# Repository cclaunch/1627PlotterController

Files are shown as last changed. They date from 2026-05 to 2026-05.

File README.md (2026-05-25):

Attaching a 1627 Plotter to an IBM 1130 system required the installation of an IBM double width SLT card 5806223 into
gate A-C1 in slots M4/M5. The 1627 was an IBM badged version of the Calcomp 565 or 563 plotters.

This project provides a functional equivalent to that IBM SLT card that can be plugged into the IBM 1130 to add 
the controller logic so that software can command plotter movements and see its status in the same way as
the IBM card. PCBWay.com sponsored production of the main printed circuit board 
during development of this project. The results were excellent.

A connector is built to plug into the 1130 card compartment to wire the plotter into the system, 
in conjunction with an SMS power paddle card to plug into the SMS power connector block.

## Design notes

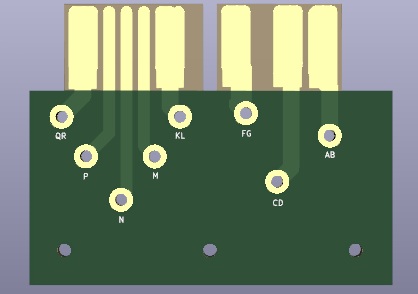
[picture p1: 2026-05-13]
sms power image.jpg

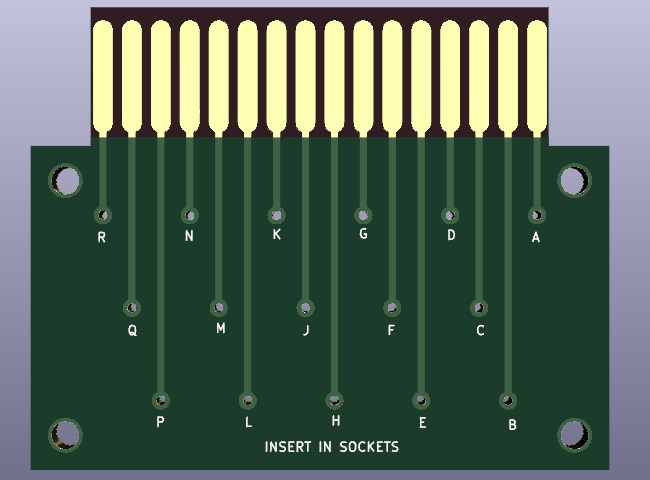
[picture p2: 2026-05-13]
sms signal paddle image.jpg

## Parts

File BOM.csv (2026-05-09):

Index | DigiKey Part # | Manufacturer Part Number | Manufacturer | Description | Quantity | Unit Price | Extended Price
1 | 1286-1205-ND | 410-376 | DIgilent | CMOD S7: BREADBOARDABLE SPARTAN7 | 1 | $99.00 | $99.00
2 | 497-6447-2-ND | LD1117S50TR | STM Microelectronics | IC REG LINEAR 5V 1.2A SOT-223 | 1 | $0.39 | $0.39
3 | 1276-1066-1-ND | CL21B105KAFNNNE | Samsung | CAP CER 1UF 25V X7R 0805 | 2 | $0.08 | $0.16
4 | RR12P1.0KDCT-ND | RR1220P-102-D | Susumu | RES SMD 1K OHM 0.5% 1/10W 0805 | 6 | $0.04 | $0.22
5 | 296-1630-1-ND | SN74LS05DR | Texas Instruments | IC INVERTER 6CH 1-INP 14SOIC | 1 | $0.83 | $0.83
6 | 296-14877-1-ND | SN74LS07DR | Texas Instruments | IC BUFF NON-INVERT 5.25V 14-SOIC | 1 | $0.59 | $0.59
7 | 20KDACT-ND | ERA-6AEB203V | Panasonic | RES SMD 20K OHM 0.1% 1/8W 0805 | 1 | $0.14 | $0.14
8 | A129757CT-ND | CRGCQ0805F4K7 | TE Connectivity | RES 4.7K OHM 1% 1/8W 0805 | 1 | $0.10 | $0.10
9 | RC0805FR-071K69L | RC0805FR-071K69L | Yageo | RES 1.69K OHM 1% 1/8W 0805 | 1 | $0.10 | $0.10
10 | RC0805FR-071K8L | RC0805FR-071K8L | Yageo | RES 1.8K OHM 1% 1/8W 0805 | 1 | $0.10 | $0.10
11 | ERA-6AEB332V | ERA-6AEB332V | Panasonic | RES SMD 3.3K OHM 0.1% 1/8W | 1 | $0.10 | $0.10
12 | KGM21NR71H104KT | KGM21NR71H104KT | Kyocera | CAP CER 0.1UF 50V X7R 0805 | 3 | $0.08 | $0.24
13 | A1921-ND | 640456-2 | TE Connectivity | CONN HEADER VERT 2POS 2.54MM | 1 | $0.13 | $0.13
14 | JLCPCB.com | W202411242236863 | Carl Claunch | SMS power card | 1 | $4.47 | $4.47
15 | ebay | SK19-23C | Cannon | Cannon 19 pin cable connector female | 1 | $23.49 | $23.49
16 | Mouser 571-1-102056-2 | 1-102056-2 | TE Connectivity | MODIV 24 pin connector | 1 | $6.39 | $6.39
17 | Mouser 571-1044808 | 104480-8 | TE Connectivity | socket pins 26-22 AWG | 24 | $0.33 | $7.94
 |  |  |  | Fedex Digikey and Mouser shipment charge | 2 | $6.99 | $13.98
 |  |  |  | tax @ 7% |  |  | $10.11
 |  |  |  | PCB + shipping charge | 0.2 | 74 | $14.80
 |  |  |  |  |  | subtotal | $183.28

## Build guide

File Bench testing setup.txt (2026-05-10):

Using Arduino Uno driver to bench test the plotter controller card

OVERVIEW
This code will drive signals that can put the plotter controller card
through its paces. The Uno produces 5V signals, so level shifting is
recommended via an open collector buffer chip and pullup resistor.

Six inputs on the analog pin side of the UNO are used with pushbuttons
to activate one of the actions. They have an internal pullup thus 
the pushbutton needs to have the input grounded except when pressed.

The reset button will put the card in a reset as occurs when the 1130
powers up or when the RESET button on the 1130 console is depressed.

The do drum up button will command the plotter to move the drum up one
position, followed by an XIO Sense Device so that you can verify
the busy bit (14) is set and operation complete (0) is not set
in the DSW. The interrupt request output pin of the controller
card will not go active low until 3.8 ms (5.8 ms when model 2
jumper is installed). Interrupt request stays low until the
state is reset by pushing the sense reset button. 

The do raise button will command the plotter to raise pen up off
the paper, followed by an XIO Sense Device while the plotter
is still considered busy. The interrupt request pin on the 
controller card will not go active (drop to low) until 100 
ms has elapsed. 

The sense button will issue an XIO Sense Device to the plotter
controller card, with the output pins on the card dropping
DSW bit 0, DSW bit 14 and DSW bit 15 when those bits of the 
DSW are a 1. 

The sense reset button will issue an XIO Sense Device to 
the plotter with the reset bit 15 set in the IOCC. This 
will reset the interrupt request for level 3 - an output
pin on the controller card - returning it to logic high. 
The DSW will not have bit 0 active since the completion 
was just reset. 

The do pen right and pen lower button will command both
movements simultaneously. The pen right output pin on the controller
card will drop low for 1.9 ms (2.9 ms if the model 2 jumper
is installed on the card) then go back to logic high, but
the lower pen output pin will stay low for 50 ms. The
interrupt request pin on the card will not go low (active)
until 100 ms has passed. 

REQUIREMENTS
Arduino Uno
12V power supply
3V power supply
-24V power supply
two open collector hex buffer chips
method to connect to SLT card pins
4 pullup resistors 10K 
Oscilloscope or logic analyzer to see outputs
the controller card to be tested

OUTPUT PINS ON THE ARDUINO
0    N/C
1    N/C
2    T6
3    XIO Sense Device
4    XIO Sense Devices w/Reset 15
5    DC Reset
6    B Bit 0
7    B Bit 1
8    B Bit 2
9    B Bit 3
10   B Bit 4
11   B Bit 5
12   XIO Write
13   Area 5

INPUT PINS ON THE ARDUINO
buttons on breadboard to Arduino
with internal pullup activated
14/A0   reset
15/A1   do drum up
16/A2   do raise pen
17/A3   Sense
18/A4   Sense reset 15
19/A5   do pen right and pen lower

OUTPUT PINS ON THE CONTROLLER CARD
these are of different logic voltage levels. 
Some require an external pullup resistor.

Interrupt request B09 needs a pullup to 3V
DSW Bit 0 B10 needs a pullup to 3V
DSW Bit 14 B04 needs a pullup to 3V
DSW Bit 15 B05 needs a pullup to 3V

Pen Left J04 is inverted logic, at 12V except 0 when active
Pen Right G05 is inverted logic, at 12V except 0 when active
Drum Up J02 is inverted logic, at 12V except 0 when active
Drum Down J05 is inverted logic, at 12V except 0 when active
Pen Up D05 is inverted logic, at 12V except 0 when active
Pen Down D04 is inverted logic, at 12V except 0 when active

The controller card needs 12V supplied to pin G02 and ground
attached to pins D08 and J08. It will consider the plotter
to be offline and not ready unless -24V is fed through a 3.9K
resistor to pin B08. When that voltage through the resistor
is present, the controller will issue outputs to move
the plotter pen and drum. DSW bit 15 is logically 1 (0V)
if no voltage present on B08, logic 0 (3V) if -24 there.

INPUT PINS ON THE CARD
The attachments from the Arduino are level shifted to 
3V through the buffer chips in your bench test setup

XIO Write          J12
Area 5             J10
T6                 J13
DC Reset           D12
Sense Device       D07 and D11
Sense Reset bit 15 D09
B bit 0            B03
B bit 1            D10
B bit 2            D02
B bit 3            D13
B bit 4            D06
B bit 5            B02

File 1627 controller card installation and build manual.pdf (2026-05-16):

## Build and Installation Instructions

1627 Plotter attachment to IBM 1130

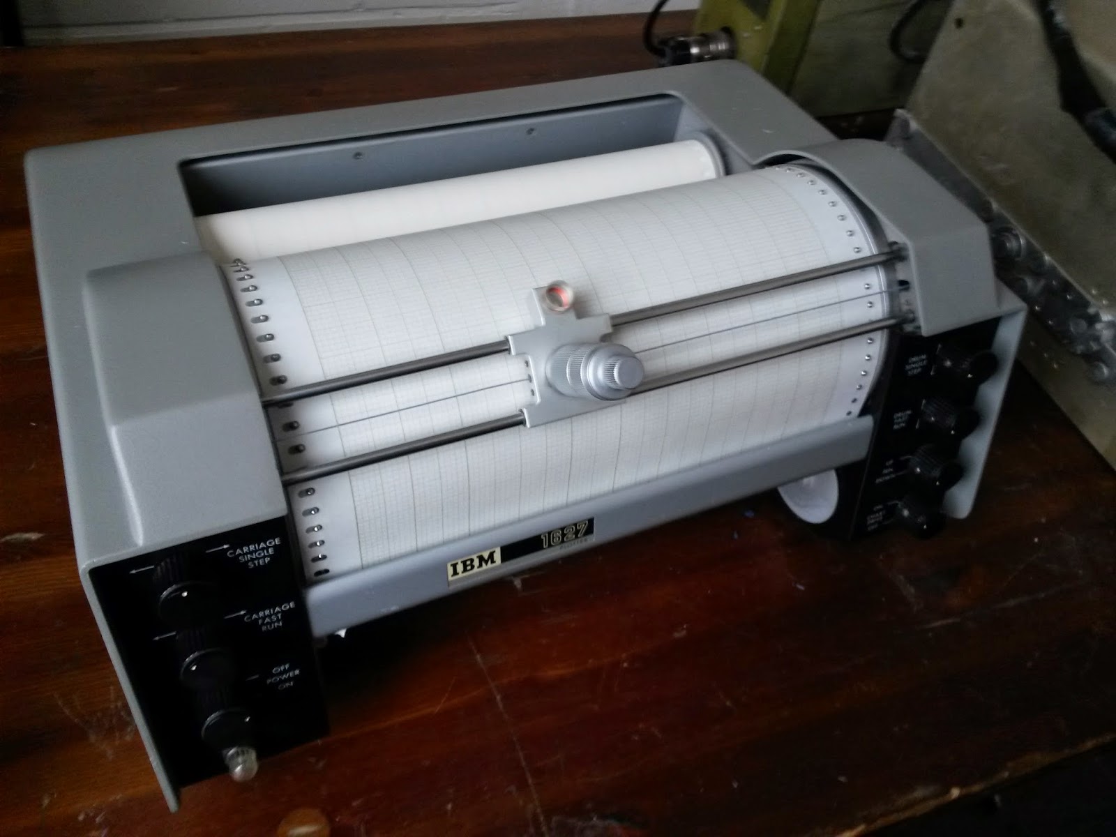
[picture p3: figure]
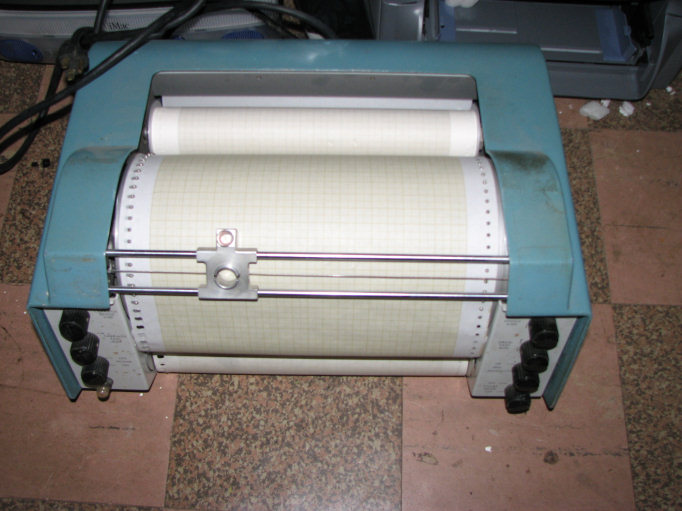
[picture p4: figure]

Carl V Claunch | 1 | Version 1

Plotter models this board can be used with

This board is designed to be used with the IBM 1627 model 1 or IBM 1627 model 2 plotters. These are private labeled versions of the Calcomp 565 and Calcomp 563 respectively.

Selecting the plotter model

To support the larger plotters - 1627 model 2 or Calcomp 563 - install a jumper across the two pins marked ‘model 2’ on the PCB. The jumper slows down the response to pen movements from 3.8 milliseconds to 5.8 milliseconds due to the larger drum size of those models. If the plotter is an IBM 1627 model 1 or a Calcomp 565, no jumper is installed on the pins.

1627 Plotter attachment to IBM 1130

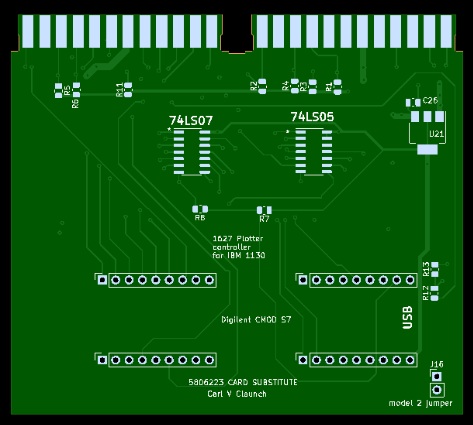
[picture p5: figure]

Carl V Claunch | 2 | Version 1

Building the card

It is recommended that the contacts be installed onto the printed circuit board before adding the other components. See the following section for how to source the contacts and how to solder them onto the board.

Next solder the resistors, capacitors and three integrated circuits on the PCB. The last step will be to install the daughterboard onto the PCB. Push the Digilent CMOD S7 FPGA board through the holes, ensuring that you have the USB connector end oriented properly. This board must lay low on the PCB to avoid mechanical interference with other SLT cards when it is in the compartment. Solder the FPGA board in place and trim the leads close to the back of the main PCB.

If not done already, the plastic covers are inserted over the two sockets and snapped into place. The card would then be ready for bench testing, installation in the IBM 1130 and testing on the system.

1627 Plotter attachment to IBM 1130

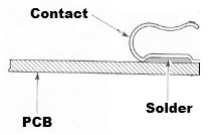
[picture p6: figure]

Carl V Claunch | 3 | Version 1

Installing contacts and cover on the substitute card

The card has space for 48 contacts to form the two 2x12 slot plugs. Generally the best way to get the contacts is to disassemble a donor Solid Logic Technology (SLT) card.

Remove the plastic cover over the 2x12 pin socket from which you can extract 24 contacts. The edges of the card slope outward toward the end which tends to hold the plastic cover in place. A small screwdriver can be used to bend the sides of the covers to allow them to be pulled off the card. Also save the plastic cover for re-use on the new card.

Unsolder contacts from the donor card(s) until you have the 48 needed for the plotter substitute controller card. A hot air rework tool on a heated rework table works best for this, but use any method you have that works.

The contact has a flat plate that solders onto the PCB pad and continues bending around and upward to provide a springy bit of metal that the SLT backplane pin can push against. Do not install the contact with the bend at the edge of the card, the open U shape should be at the edge.

1627 Plotter attachment to IBM 1130

Carl V Claunch | 4 | Version 1

First, using a solder paste with a higher melting point (e.g. 183 C), solder down the contacts on one side. Set the rework table to about 150 C and a hot air rework gun to over 183 C.

Lay solder paste on the pads on the side of the card you are working with first, then place all the contacts on that side sitting in roughly the correct position atop the paste.

Using the hot air rework gun, melt the pads while verifying that the contact slides into proper alignment once the solder has fully flowed. Work from one side to the other, until you have all the contacts lined up correctly and soldered to the board. A clamp or clip might be placed on the contact portion directly on the PCB pad, with the other side of the clamp/clip on the underneath portion of the PCB. That would assure better alignment but the key will be to heat long enough to be certain the solder paste is fully melted underneath the contact.

Using a second lower heat solder paste (e.g. 138 C), turn the rework table down to about 115C and the hot air rework gun to just a bit over 138
C. Once the table is at the proper temperature, lay the card with the other side’s pads facing you. Lay solder paste on the pads and place the remaining contacts in approximately the proper spot. If using a clamp or clips, add them now.

Using the hot air rework gun, melt the pads while verifying that the contact sits in proper alignment once the solder has fully flowed. Work from one side to the other, until you have all the contacts lined up correctly and soldered to the board.

1627 Plotter attachment to IBM 1130

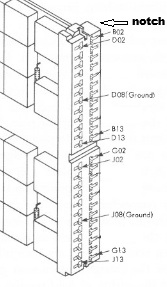
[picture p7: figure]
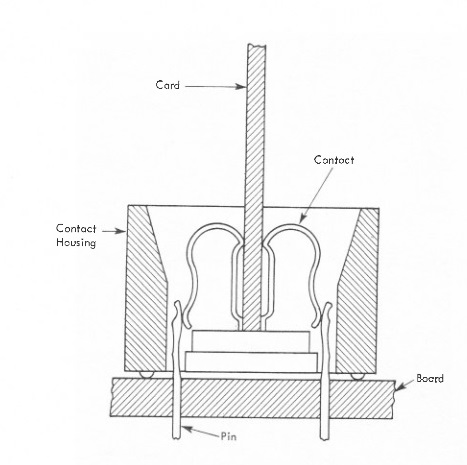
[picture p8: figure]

Carl V Claunch | 5 | Version 1

Slide the plastic covers over the contacts to finish the SLT slot plugs. The notch on the cover is on the side of the PCB away from the chips.

Do a test insertion into a vertical pair of open SLT slots in the 1130 to confirm that the card does snap down into place.

1627 Plotter attachment to IBM 1130

Carl V Claunch | 6 | Version 1

Load the logic into the FPGA

Load the CMOS S7 FPGA board with the memory configuration file to activate the logic for the plotter controller functionality. I use Xilinx Vivado, doing an autoconnect to the board through a USB cable, selecting the flash RAM that is listed as part of the discovered board, then programming the FPGA with the memory configuration file.

If the flash RAM chip on the CMOD S7 board is a MX25L3233F, then the FPGAload.mcs file included in the github project can be downloaded, otherwise a project must be built in Vivado to synthesize and generate the bitstream from the source files, then creating a memory configuration file to download to the RAM chip type that is built into your CMOD S7 board. A file on github explains how to generate IP and add additional source files to build the memory configuration file.

If you might ever use the USB serial link to capture movement commands from the card, there is a hardware modification needed to the CMOD S7 board (see later in this document) to safely connect when the card is in the IBM 1130.

Installing the substitute 5806223 controller card in the 1130

Once you are done with any visual inspection, continuity testing and possible bench testing, slide the double width card into slots M4 and M5 of Gate A, Compartment C1. Push down until it is securely in place.

1627 Plotter attachment to IBM 1130

Carl V Claunch | 7 | Version 1

Three alternative approaches to connecting the 1627 cable

A - The IBM 1130 system already has cabling installed between Gate A, Compartment C1, Slot N5 and slot PF6 of the SMS sockets for peripherals inside the 1130 system

B - you will wire up a cable between SMS socket slot PF6 and Gate A, Compartment C1 Slot N5

C - you will wire up a modern connector near Gate A, Compartment C1 into which the plotter signal cable will plug

1627 Plotter attachment to IBM 1130


Carl V Claunch | 8 | Version 1

Alternative A - using existing wiring in an 1130 system

Since the 1130 already has wiring from a socket in slot PF6 of the SMS peripheral connection block over to Slot N5 of Gate A, Compartment C1, you only need to connect the wiring from the plotter connector to an SMS paddle card that will be plugged into slot PF6.

A female 19 pin connector, Cannon SK19-23C, plugs into the rear of the plotter. It carries all the power and signal lines between the plotter and the 1130 system.

Create an SMS power paddle card and run 18 gauge stranded wire to it from the 19 pin connector:

Cannon pin 15 is connected to pad P of the power paddle card Cannon pin 17 is wired to pads F and G of the power paddle card Cannon pin 18 is wired to pads C and D of the power paddle card Cannon pin 14 is wired to pads K and L of the power paddle card

A SMS power paddle card has a notch cut in the card approximately where pads H and J would be on a normal SMS signal paddle card. This ensures that signal cards CANNOT fit into the power SMS sockets on the 1130 system. Gerber/drill files are provided to make this card as well as files to make an SMS signal paddle card used below.

1627 Plotter attachment to IBM 1130

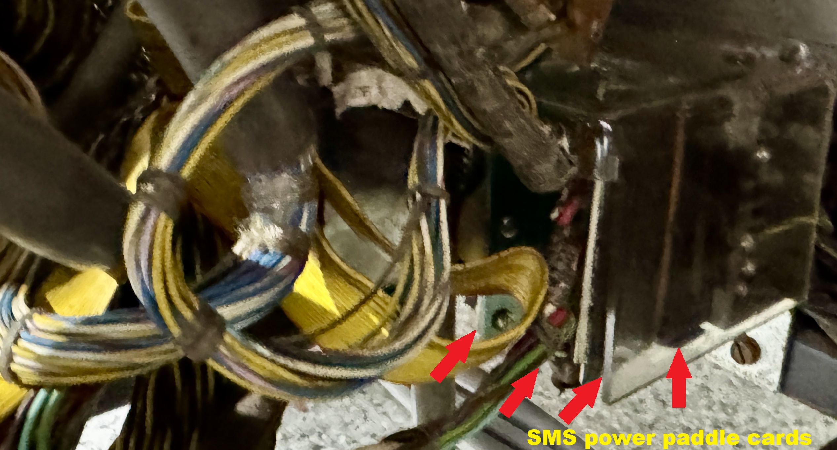
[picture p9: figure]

Carl V Claunch | 9 | Version 1

A regular SMS paddle card, used for the signal connections, is connected as follows using smaller gauge stranded wire:

Cannon pin 5 is wired to the signal paddle card PF6 pad R Cannon pin 6 is wired to the signal paddle card PF6 pad Q Cannon pin 7 is wired to the signal paddle card PF6 pad N Cannon pin 8 is wired to the signal paddle card PF6 pad P Cannon pin 11 is wired to signal paddle card PF6 pad M
Cannon pin 12 is wired to signal paddle card PF6 pad L
Cannon pin 16 is wired to signal paddle card PF6 pad G

Install a 3.9K resistor connected between PF6 pad G and PF6 pad C

Open the lower SMS socket block inside the IBM 1130, where peripheral power connections are made. Insert the power paddle card you manufactured into slot PP6. The correct slot is important as the power connections in the block can vary by location. . Close up the power socket block.

1627 Plotter attachment to IBM 1130

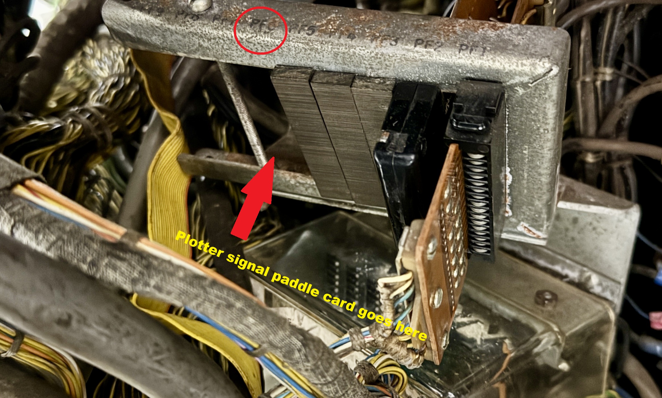
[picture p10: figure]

Carl V Claunch | 10 | Version 1

Open the upper SMS socket block that connects signal lines to peripherals. Insert the signal paddle card into slot PF6 of this block. Close up the socket block.

1627 Plotter attachment to IBM 1130

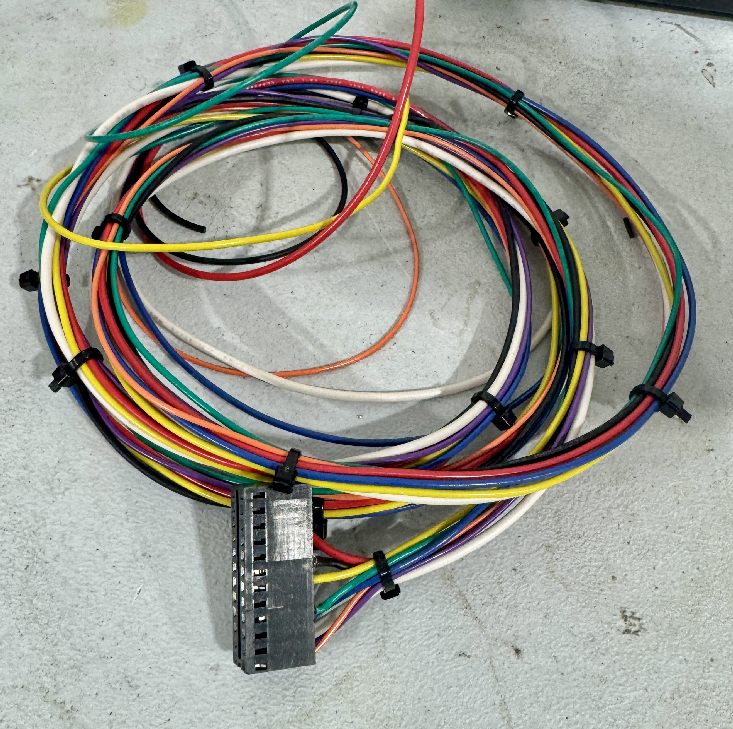
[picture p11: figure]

Carl V Claunch | 11 | Version 1

Alternative B - Adding wiring that matches the IBM approach

Construct the two paddle cards and the cable to the Cannon 19 pin connector using the instructions from Alternative A above. The additional work that must be done is to add a wire bundle between the SMS signal socket block slot PF6 and Gate A, Compartment C1, Slot N5 where the signals are connected to the Solid Logic Technology (SLT) backplane for that compartment.

Build an SLT connector that will plug into slot N5 - a source is provided in the bill of materials.

Using appropriate twisted pairs, routing one wire of each pair to the 1130 signal ground, connect:

Paddle socket position R is wired to N5 connector position B02 Paddle socket position Q is wired to N5 connector position D02 Paddle socket position N is wired to N5 connector position D04 Paddle socket position P is wired to N5 connector position B03 Paddle socket position M is wired to N5 connector position B04 Paddle socket position L is wired to N5 connector position D05 Paddle socket position C is wired to N5 connector position B10

1627 Plotter attachment to IBM 1130

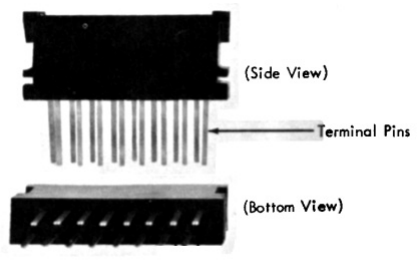
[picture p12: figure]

Carl V Claunch | 12 | Version 1

Install the female SMS socket in space PF6 of the upper SMS socket block. Plug the SMS signal paddle card you wired from the plotter (as covered in alternative A) into this socket. Close up the SMS signal socket block.

Plug the SLT connector end you just wired to the SMS female socket into Gate A, Compartment C1, Slot N5. See the instructions further down for how to do this.

1627 Plotter attachment to IBM 1130

Carl V Claunch | 13 | Version 1

Alternative C - modern connector for the signal connections

Use the instructions from alternative A to build an SMS power paddle card and wire it to the Cannon 19 pin connector. Install the SMS power paddle card in the lower SMS socket block as described in alternative A.

Buy any 8 pin male and female socket pair. Install the female socket on the 1130 gate A near Compartment C1. Build the SLT socket as described in alternative B.

Wire the 19 pin connector to the male socket:
Cannon pin 5 is wired to the socket pin 1
Cannon pin 6 is wired to the socket pin 2 Cannon pin 7 is wired to the socket pin 3 Cannon pin 8 is wired to the socket pin 4
Cannon pin 11 is wired to the socket pin 5
Cannon pin 12 is wired to the socket pin 6
Cannon pin 16 is wired to a 3.9K resistor whose other end is wired to the socket pin 7
Cannon pin 15 is wired to the socket pin 8 (also wired to the power SMS paddle card)

Connect the female socket:
socket pin 1 to N5 connector position B02
socket pin 2 to N5 connector position D02 socket pin 3 to N5 connector position D04 socket pin 4 to N5 connector position B03 socket pin 5 to N5 connector position B04
socket pin 6 to N5 connector position D05
socket pin 7 to N5 connector position B10
socket pin 8 to signal ground below the card compartment

1627 Plotter attachment to IBM 1130

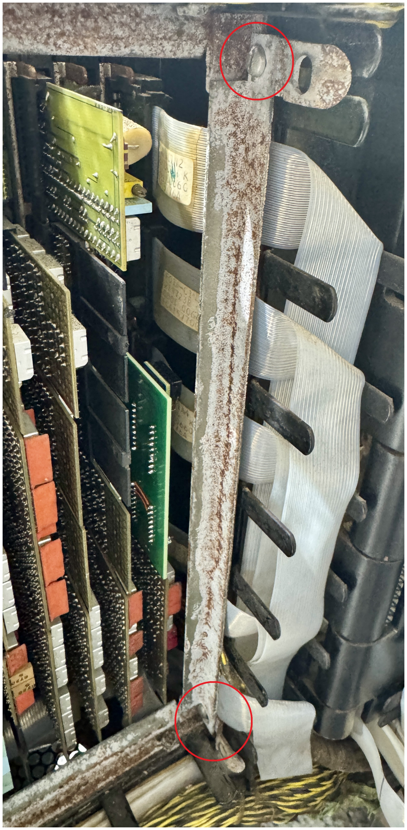
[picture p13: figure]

Carl V Claunch | 14 | Version 1

Installing the SLT connector in slot N5

Remove the card cover from compartment C1 of gate A. Loosen the two screws circled in red below that hold the right side support for the cover.

Plug the SLT connector into slot N5 and pass the wires to the right so that they will be held under the right side support when you re-install that part.

Secure the cable from the male connector where it exits the 1130 system to protect from someone accidentally pulling the connectors. I used twist ties to anchor the cable inside compartment C1 after the connector was plugged in, as well as anchoring the cable as it runs through the 1130 and at the exit point where the cable comes out of the machine.

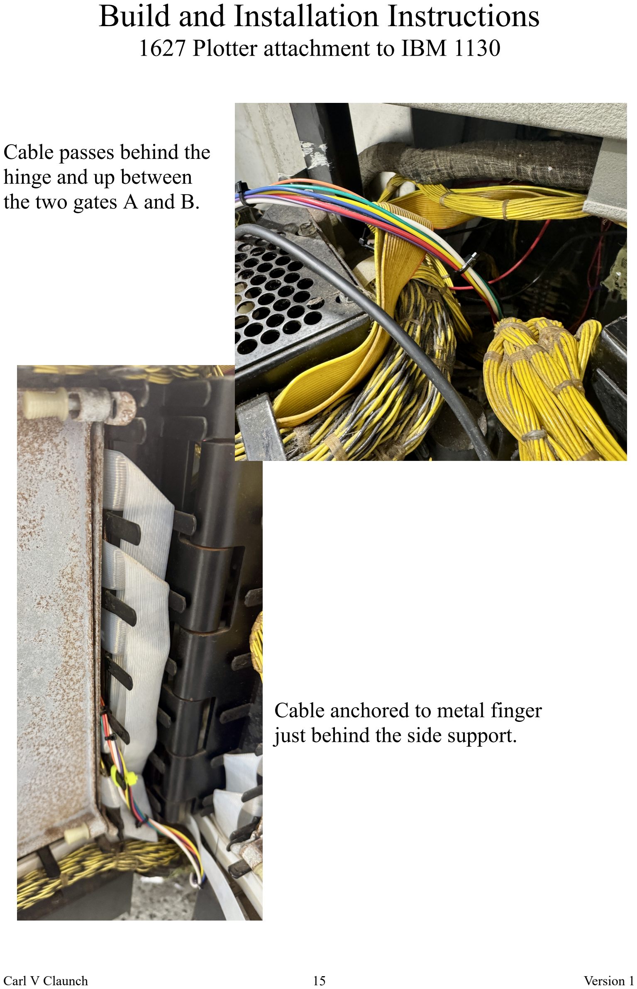
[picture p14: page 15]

1627 Plotter attachment to IBM 1130

Carl V Claunch | 15 | Version 1

Cable passes behind the
hinge and up between
the two gates A and B.

Cable anchored to metal finger just behind the side support.

1627 Plotter attachment to IBM 1130

Carl V Claunch | 16 | Version 1

Building an SLT cable connector to wire in the plotter

This cable will can be built two ways - so that it can be hooked to the SMS signal connector block inside the 1130 allowing the SMS paddle card to be used to hook up the plotter, or directly to the connector that fits on the plotter. For alternatives B or C, you must create a connector to plug into Slot N5 of Gate A, Compartment C1 of the 1130. Alternative A is for a system with the connector already in place and wired, thus skip this step.

Using the parts listed in the Bill of Materials, crimp the socket pins onto the wire ends and insert the pins into the plastic housing in the appropriate spots.

1627 Plotter attachment to IBM 1130

Carl V Claunch | 17 | Version 1

Testing the card with a bench setup

The file Bench testing setup.txt covers the process of building a test setup on the bench and testing the card before inserting it into the IBM 1130. This step can be skipped if you are comfortable that the card is properly constructed and free of short circuits.

Testing the plotter with the 1130

With the plotter connected but power off, execute an XIO instruction pointing to an IOCC that specifies a Sense Device operation and area code 5. The result in the accumulator register (ACC) will be the Device Status Word (DSW). Bit 15 should be 1, indicating that the controller card is present but the plotter is not ready to accept commands.

Turn on the plotter power and issue the same XIO instruction. The DSW should have all bits off, indicating that the plotter is ready to be used.

Set up an XIO instruction pointing to an IOCC that specifies a Write operation, area code 5, and points to a word which has the intended movement command. The six leftmost bits of that word specify the movement you wish the plotter to make, with a 1 in the position indicating that movement should be made.

Bit 0 requests that the pen be lowered onto the paper
Bit 1 requests that the drum turn down one position
Bit 2 requests that the drum turn up one position Bit 3 requests that the pen move right one position Bit 4 requests that the pen move left one position Bit 5 requests that the pen be raised off the paper

1627 Plotter attachment to IBM 1130

Carl V Claunch | 18 | Version 1

In single step mode, execute that XIO instruction with your desired movement. Verify that the plotter moved as expected. Verify that the interupt level 3 light on the console display pedestal is illuminated.

The next address executed will be the interrupt handler for level 3. In memory location 000B is an address for the interrupt handler. The hardware will store the address from which we were interrupted into the first word of the interrupt handler and then execute the instruction in the second word of the handler.

If you press the RESET button on the 1130 console, the interrupt request for level 3 should go away.

Next, code two XIO instructions and a Halt instruction in sequence. Open the top cover of the 1130 and turn on the Interrupt Delay switch. The first XIO points to the IOCC which specifies Write to area 5 pointing at a word with your desired movement set in bits 0 to 5. The second XIO points to an IOCC which specifies Sense Device with area 5.

Set the 1130 into run mode, point the IAR at the first XIO instruction, and push the PROG START button on the console. The plotter should move as you requested, the interrupt request lamp for level 3 should be illuminated and the ACC should display a DSW with bits 0 and 14 turned on. This indicates operation complete (0) and that the plotter was still busy at the time we issued the Sense Device.

Set the IAR to the second XIO instruction and push PROG START again. The ACC should now display a 1 only in bit 0, operation complete, but without the busy bit (14) turned on.

1627 Plotter attachment to IBM 1130

Carl V Claunch | 19 | Version 1

Set up an XIO instruction pointing to an IOCC specifying a Sense Device for area 5. Bit 15 of the second word of the IOCC should be set to
1. This specifies reset bit 15. Set the 1130 mode to Single Instruction and set the IAR to this XIO instruction. Push the PROG START button.

The interrupt request lamp for level 3 should be turned off. The DSW should have all 0 bits indicating that the plotter is now ready for the next command and that the operation complete was reset.

Try all six of the bits for movement commands, verifying that each on works as intended. That should be sufficient to verify that the controller card is working properly. Optionally one could load the IBM diagnostic program for the 1627 plotter and run it as described in the A0x ALD that covers this diagnostic program.

1627 Plotter attachment to IBM 1130

Carl V Claunch | 20 | Version 1

Connecting an optional USB serial link cable

A mini USB connector on the board provides a stream of ASCII lines, one per XIO Write issued to the plotter. Route the cable from the end of the card out of Compartment C1 and out of the IBM 1130 system.

Hooking the other end of the cable into a PC, Mac or workstation that supports serial over USB provide the ability to capture every movement issued to the plotter. Software in that external computer can interpret those movements to draw the same image as is appearing on paper in the plotter.

This may draw the image in real time on a screen or produce a graphic file. The data is in ASCII, running at 38,400 baud, 8 bit, no parity, 1 stop bit. Each line is a set of six ASCII 0 or 1 characters for the six bits sent by the XIO Write command, followed by a CR and then an NL character. For example, a command to lower the pen onto the paper would output this line - 100000 (nl) (cr) on the serial link.

1627 Plotter attachment to IBM 1130

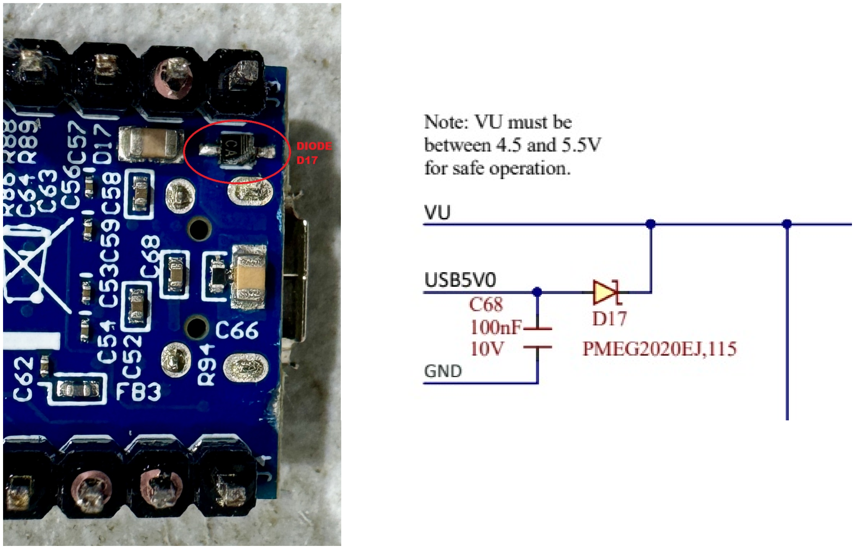
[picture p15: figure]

Carl V Claunch | 21 | Version 1

Modifying the CMOD S7

To eliminate the issue of dual powering for the CMOD S7 board - the regulator on my card and the USB connection - we will remove diode D17 from the bottom of the CMOD S7, which ensures that USB power is never applied to the CMOS S7 nor to the controller card on which it is mounted.

If new logic needs to be downloaded to the configuration memory device on the CMOD S7 board, the controller card must be removed from the IBM 1130. A bench supply should deliver +12V to pin G02 of the card, with ground connected to both pins D08 and J08. The USB cable can then be plugged in and Vivado used to update the new logic into the memory chip.

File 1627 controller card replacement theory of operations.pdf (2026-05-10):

## Theory of Operation

1627 Controller Card Replacement for IBM 1130

Carl V Claunch | 1 | Version 1

Summary

This project creates a double width Solid Logic Technology (SLT) card that plugs into an IBM 1130 to provide the controller logic to connect an IBM 1627 Plotter to the 1130 system. The 1627 was private labeled by IBM with minor changes from the Calcomp 565 (1627 model 1) or Calcomp 563 (1627 model 2).

IBM supports the 1627 with SLT card 5806223 which this is designed to behave like. The 1627 is hooked into the IBM 1130 with an SMS (IBM Standard Modular System) paddle card in slot PF6 and an SMS power card that plugs into slot PP2.

The wiring from the SMS PF6 slot is routed to an SLT connector that plugs into gate A, compartment C1 slot N5. The card is plugged into the same compartment in slots M4 and M5.

This card has a daughterboard FPGA (Digilent CMOD S7) that implements the bulk of the logic.

1627 Controller Card Replacement for IBM 1130

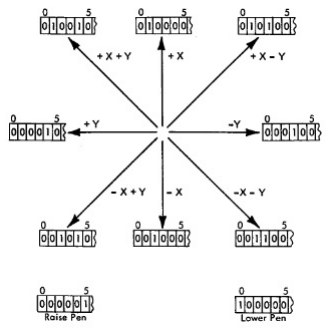
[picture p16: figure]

Carl V Claunch | 2 | Version 1

Overview of the 1627 Plotter

The plotter has a drum which pulls paper so that it moves up or down relative to the pen. The pen is on a carriage that slides left or right along the surface of the drum. The pen can be set down on the paper so that it draws on the paper or raised up. Movements are in increments of 1/100 of an inch.

Programs request movements from the 1627:

roll the drum up one position roll the drum down one position move the pen left one position move the pen right one position raise the pen from the paper lower the pen onto the paper

1627 Controller Card Replacement for IBM 1130

Carl V Claunch | 3 | Version 1

A word in memory encodes the movement requests using the top six bits of the word and ignoring the remaining bits.

When the plotter has completed a movement request and thus is ready to accept the next request, it raises an interrupt on level 3 which causes the 1130 to enter the interrupt handler software for the plotter. Typically that software will reset the interrupt request and the program using the plotter can issue a new XIO instruction to make the next movement.

The 1627 reports three status conditions to the 1130 when the XIO Sense Device instruction is issued.

Bit 0 is on when the plotter has requested in interrupt on level 3, i.e. has completed a request

Bit 14 is on when the plotter is still processing the last movement request (issued by an XIO Write instruction). It will go off when the movement finished and bit 0 is turned on.

Bit 15 is on when the 1627 is not ready to accept commands. It must be attached to the 1130 and be powered on before this bit goes away.

1627 Controller Card Replacement for IBM 1130

Carl V Claunch | 4 | Version 1

Interface between the 1130 system and the plotter

The 1627 Plotter has an 18 pin circular connector on its rear. Only pins 5, 6, 7, 8, 11, 12 and 16 are wired through to an SMS paddle card that plugs into the IBM 1130 SMS connector socket. SMS cards have contacts A, B, C, D, E, F, G, H, J, K, L, M, N, P, Q and R on the edge that mates with the socket.

Pen up is connector pin 11 hooked to paddle card M
Pen down is connector pin 12 hooked to paddle card L
Left is connector pin 7 hooked to paddle card N
Right is connector pin 8 hooked to paddle card P
Drum up is connector pin 5 hooked to paddle card R
Drum down is connector pin 6 hooked to paddle card Q

1627 -24V is wired to connector pin 16, hooked to paddle card G but is NOT connected to the 1130 wiring harness.

Instead, a 3.9K resistor is on the card between paddle card contacts G and C. Contact C is connected to the wiring harness as -24 Ready

The circular connector pins 14, 15, 17 and 18 are wired to a second SMS paddle card, this one keyed to be plugged into the SMS power connector socket on the 1130.

Connector pin 15 is the DC common (ground) connection. Connector pins 17 and 18 provide 115VAC as neutral and hot leads respectively. Connector pin 14 is the frame ground.

1627 Controller Card Replacement for IBM 1130

Carl V Claunch | 5 | Version 1

The wire harness coming from the SMS paddle card socket runs to socket N5 on the backplane in gate A, compartment C1. This is connected to pins 5, 6, 7, 8, 11, 12 and 16 of the 1627’s circular connector.

The SLT double width controller card has connections to the 1130 which are either signals generated by the card or generated by the 1130. SLT sockets have 2 rows of 12 pins and a double width card has two sockets. The first has pins D02 to D13 and B02 to B13. The second has the same pin positions labeled J02 to J13 and G02 to G13 in the same relative positions as the first socket.

inputs to the card from the 1130
SBR bits 0-5 are on pins B03, D10, D02, D13, D06 and B02 XIO Write is on pin J12
Area 5 is on pin J10
T6 is on pin J13
XIO Sense Device is on D11
XIO Sense w Reset bit 15 is on pin D09

input to the card from the 1627
-24V ready is on pin B08

outputs from the card to the 1130 DSW bit 0 on pin B10
DSW bit 14 on pin B04
DSW bit 15 on pin B05
IntLvl3 request on pin B09

1627 Controller Card Replacement for IBM 1130

Carl V Claunch | 6 | Version 1

outputs from the card to the 1627 Left (carriage left) on pin J04 Right (carriage right) on pin G05 Up (drum up) on pin J02
down (drum down) on pin J05 Pen up on pin D05
Pen down on pin D04

power connections to the cared
Ground is provided on pins D08 and J08
+12V from the 1130 is on pin G02

unused 1130 power connections on the card sockets +3V on pins D03 and J03
-3V on pins B06 and G06
+6V on pins B11 and G11

unused pins - 15 out of the 48 total on the card

1627 Controller Card Replacement for IBM 1130

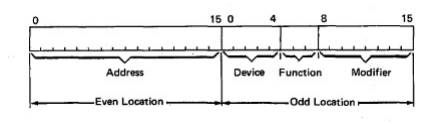
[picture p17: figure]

Carl V Claunch | 7 | Version 1

How the controller works

Input output between an IBM 1130 program and a peripheral device makes use of several facilities of the system:
XIO instruction
Interrupt handler system
device status word
cycle stealing (not used by the 1627)

The XIO instruction points to a doubleword location in memory that is interpreted as the Input Output Control Commands (IOCC). The IOCC is divided into fields:
XIO function
Read
Write
Control
Initiate Read
Initiate Write
Sense Device
Sense ILSW
Area Code or Device (device to be used) Address
Modifers

1627 Controller Card Replacement for IBM 1130

Carl V Claunch | 8 | Version 1

Miscellaneous control bits can be defined for specific devices. The address field can be used for other purposes for some devices with XIO Control.The 1627 only defines bit 15 of the modifier field as a request to reset the interrupt request raised by the controller.

The 1627 only responds to the XIO Write and XIO Sense Device functions. The address points to a memory location that contains a command for plotter movement when an XIO Write is issued.

1627 Controller Card Replacement for IBM 1130

Carl V Claunch | 9 | Version 1

Device controllers can raise a request for an interrupt. When the 1130 grants it, the processor saves the current execution location in a chosen location and begins executing code in the next word. When the program that handles this interrupt type is done, it issues a BOSC instruction which returns the CPU to the location from which it had been interrupted or to the next interrupt handler that was requested by some other device.

The 1627 is assigned to Area code 5 and only responds to XIO types Write and Sense Device. It is wired to interrupt level 3 for when it requests and interrupt handler.

The XIO Sense Device type puts a word in the 1130 Accumulator reqister with bits that are appropriate to that device. The 1627 uses only bits 0, 14 and 15 leaving the remaining bits at 0.

DSW bit 0 is used to indicate that a prior movement request to the plotter has completed. DSW bit 14 is used to indicate that the plotter is currently busy doing the movement that had last been requested. DSW bit 15 is used to indicate that the plotter is NOT attached or NOT powered on.

1627 Controller Card Replacement for IBM 1130

Carl V Claunch | 10 | Version 1

A program issues XIO Write with Area 5 to request a movement. During clock step T6 of the XIO Write, look at the contents of SBR. Any bit or combination of bits 0 to 5 in the SBR that have a 1 value will trigger the associated movement for the plotter:

bit 0 - lower the pen down to the paper
bit 1 - move drum downward
bit 2 - move drum upward
bit 3 - move pen to right
bit 4 - move pen to left
bit 5 - raise the pen up off the paper

Depending on the model of the 1627 (or Calcomp) attached, the time it takes to request a pen movement and to have it complete differs. This card is designed for the 1627 model 1 or Calcomp 565, thus times below are for those models.

Moving the drum up or down as well as moving the pen left or right requires the request to remain active from the controller card for 1.9 milliseconds and then be removed. It requires another 1.9 milliseconds for the movement to complete and stabilize.

Thus up, down, left or right movements show up as busy for 3.8 ms (DSW bit 14 is on) and at the end of the 3.8 ms a request is raised for interupt level 3.

1627 Controller Card Replacement for IBM 1130

Carl V Claunch | 11 | Version 1

Raising or lowering the pen takes the same time for all models of the 1627 or Calcomp. The request must be held active by the controller for 50 ms and then dropped. Another 50 ms is needed before the operation is considered complete and an interrupt is requested. Thus these are busy for 100 ms in total as far as DSW bit 14 and the software are concerned.

XIO Sense and Area 5 will drive status on DSW bit lines whenever the XIO Sense is issued. If the plotter is still busy then bit 14 will be set to 1. If the movement has completed and an interrupt request is active then bit 0 is set to a 1. If the Plotter is not connected and powered up, bit 15 is set to a 1 and requests are marked as immediately completed by the controller.

XIO Sense Device with the low bit on (reset 15) will turn off interrupt request in the controller card. Thus, the software for the interrupt handler must issue an XIO Sense Device to Area 5 and have reset bit 15 set to 1 in the IOCC in order to reset the request before the interrupt handler returns to normal software execution otherwise the handler is immediately re-entered.

1627 Controller Card Replacement for IBM 1130

Carl V Claunch | 12 | Version 1

Electrical interface with the 1627

The inputs for movement to the 1627 hardware use inverted logic - when no request is active they should be kept up at 12V and dropped to ground for a movement request.

The plotter hardware has a falling edge detector for the left, right, drum up and drum down commands, triggering one step of movement by the plotter hardware. Pen Raise and Pen Lower simply toggle a state flipflop and cause the mechanism to move the pen up or down appropriately to the flipflop setting.

A power supply inside the 1627 produces -24V, among other voltages, with the -24V routed back over the cable to the 1130 system. A resistor in the paddle card plus resistor voltage dividers in the controller logic convert the presence or absence of the voltage into a signal detecting whether the 1627 is powered on and connected or not.

No feedback exists from the plotter back to the controller. As long as the Plotter is emitting -24V on the connector, the controller believes it will do as requested. All the busy state generation and the interrupt request at completion are done by the controller in the blind.

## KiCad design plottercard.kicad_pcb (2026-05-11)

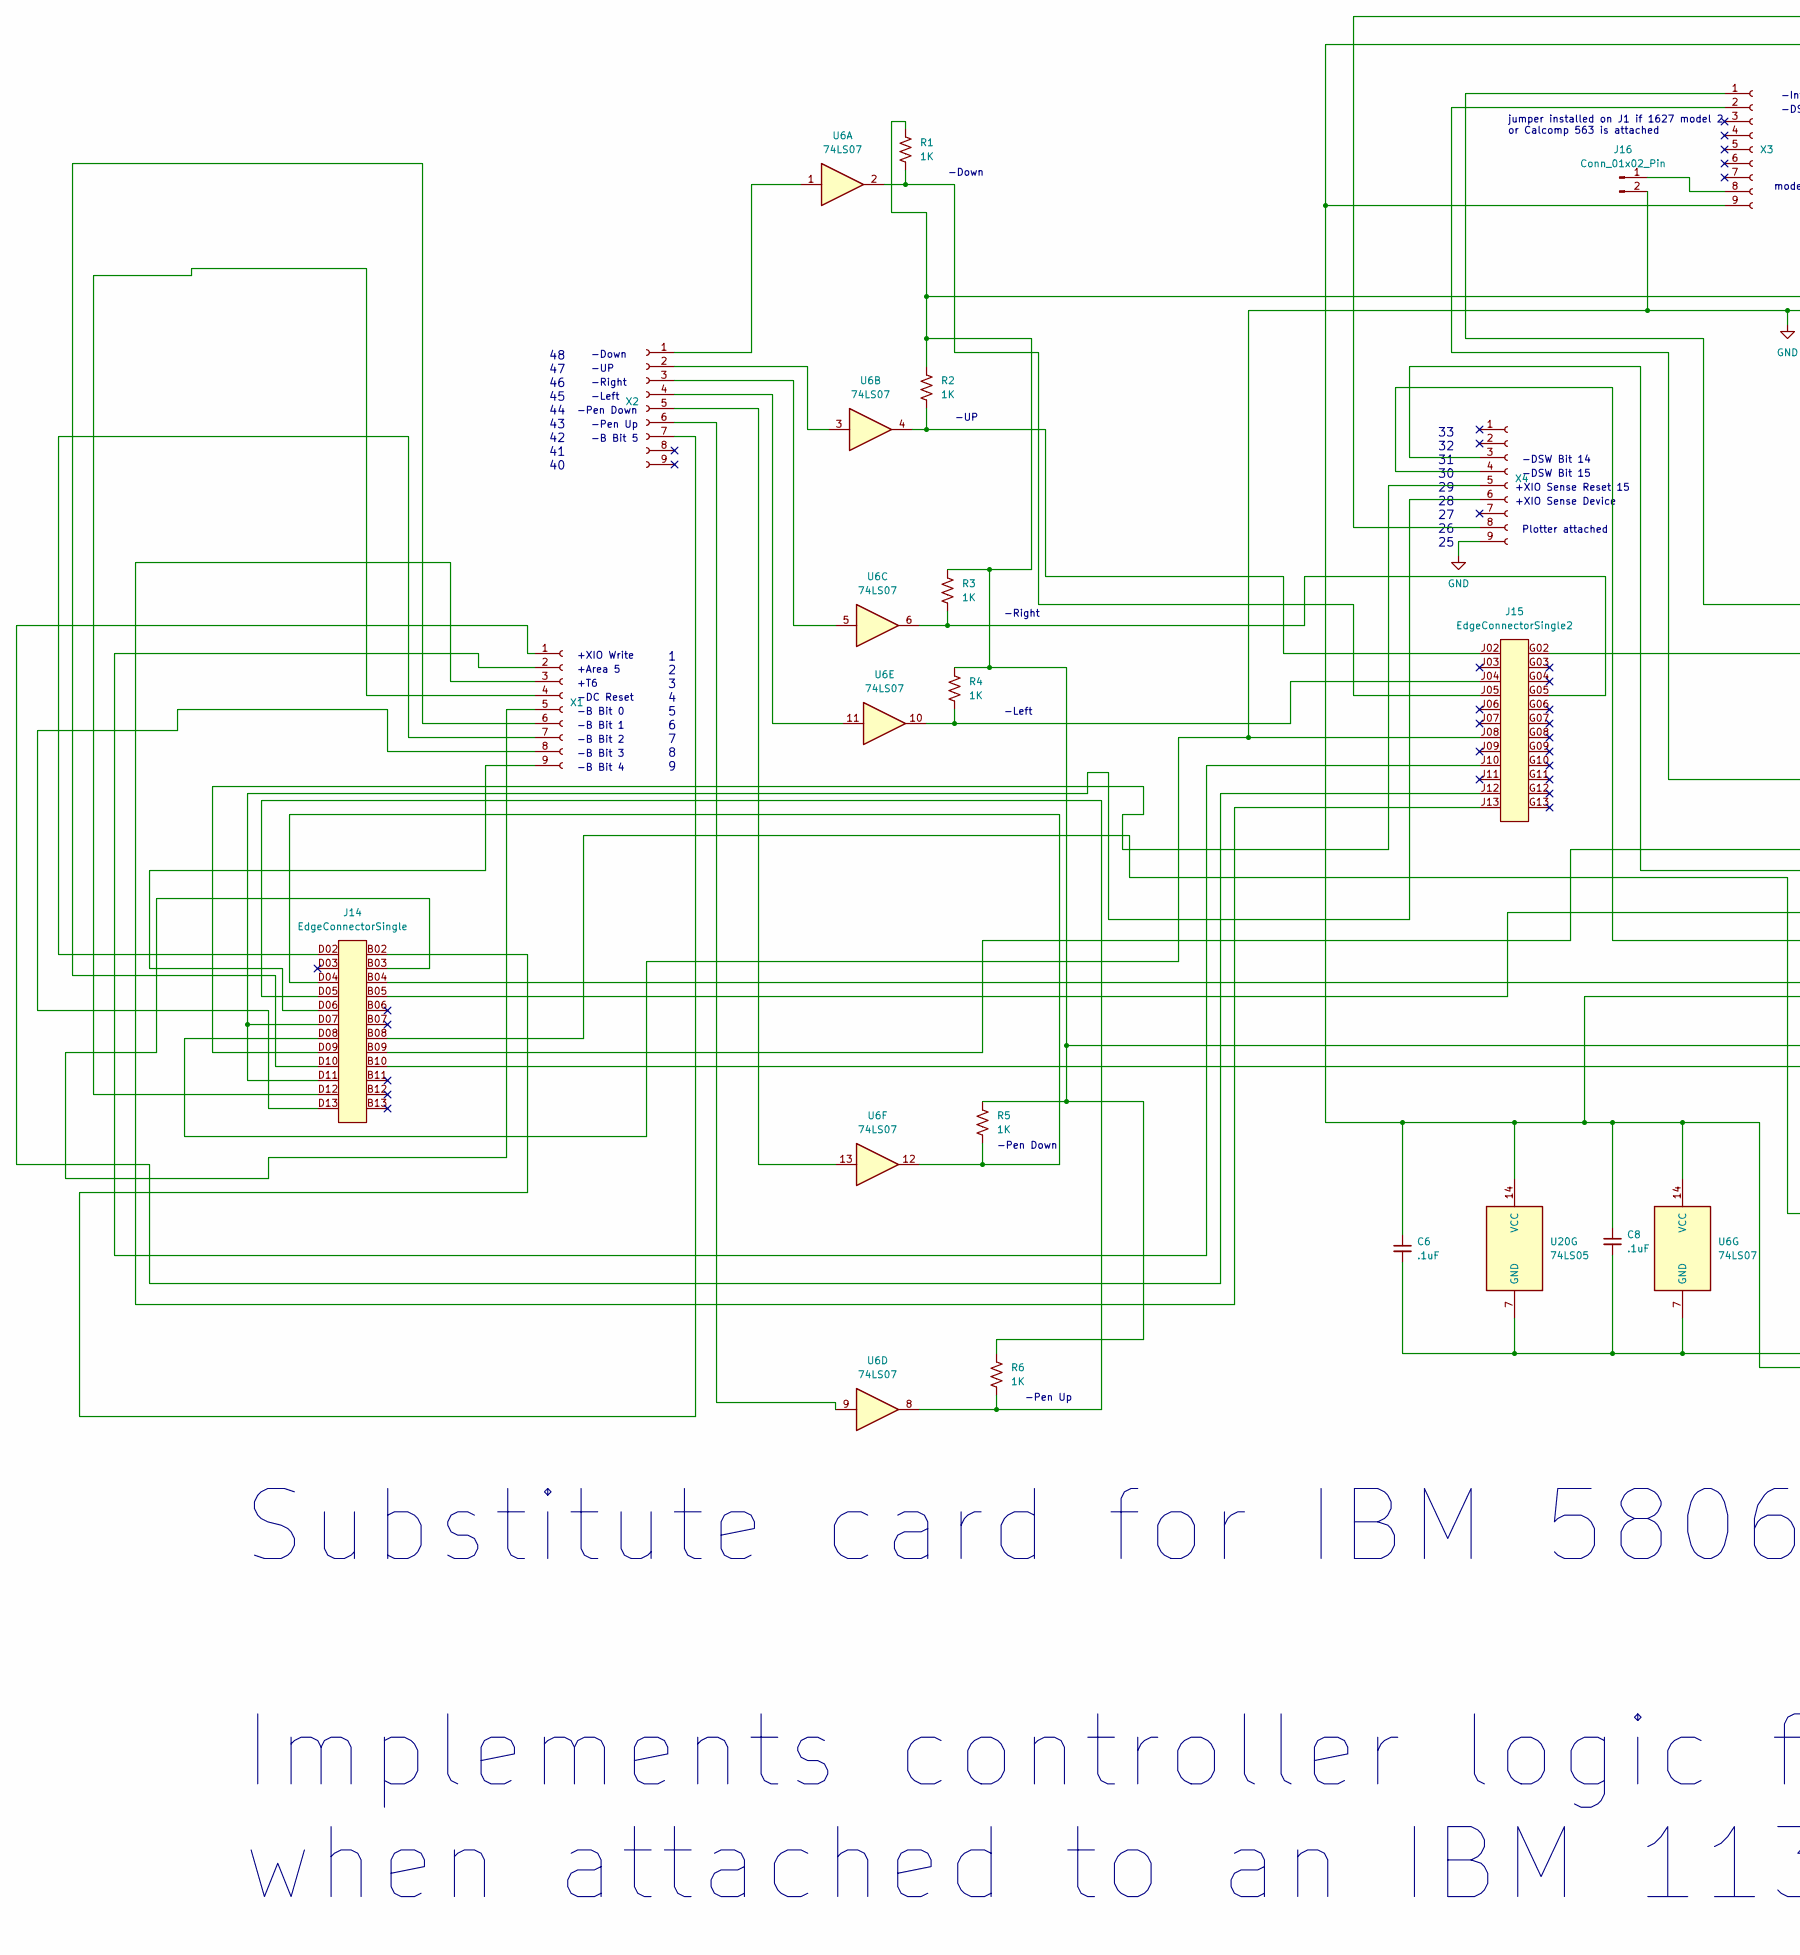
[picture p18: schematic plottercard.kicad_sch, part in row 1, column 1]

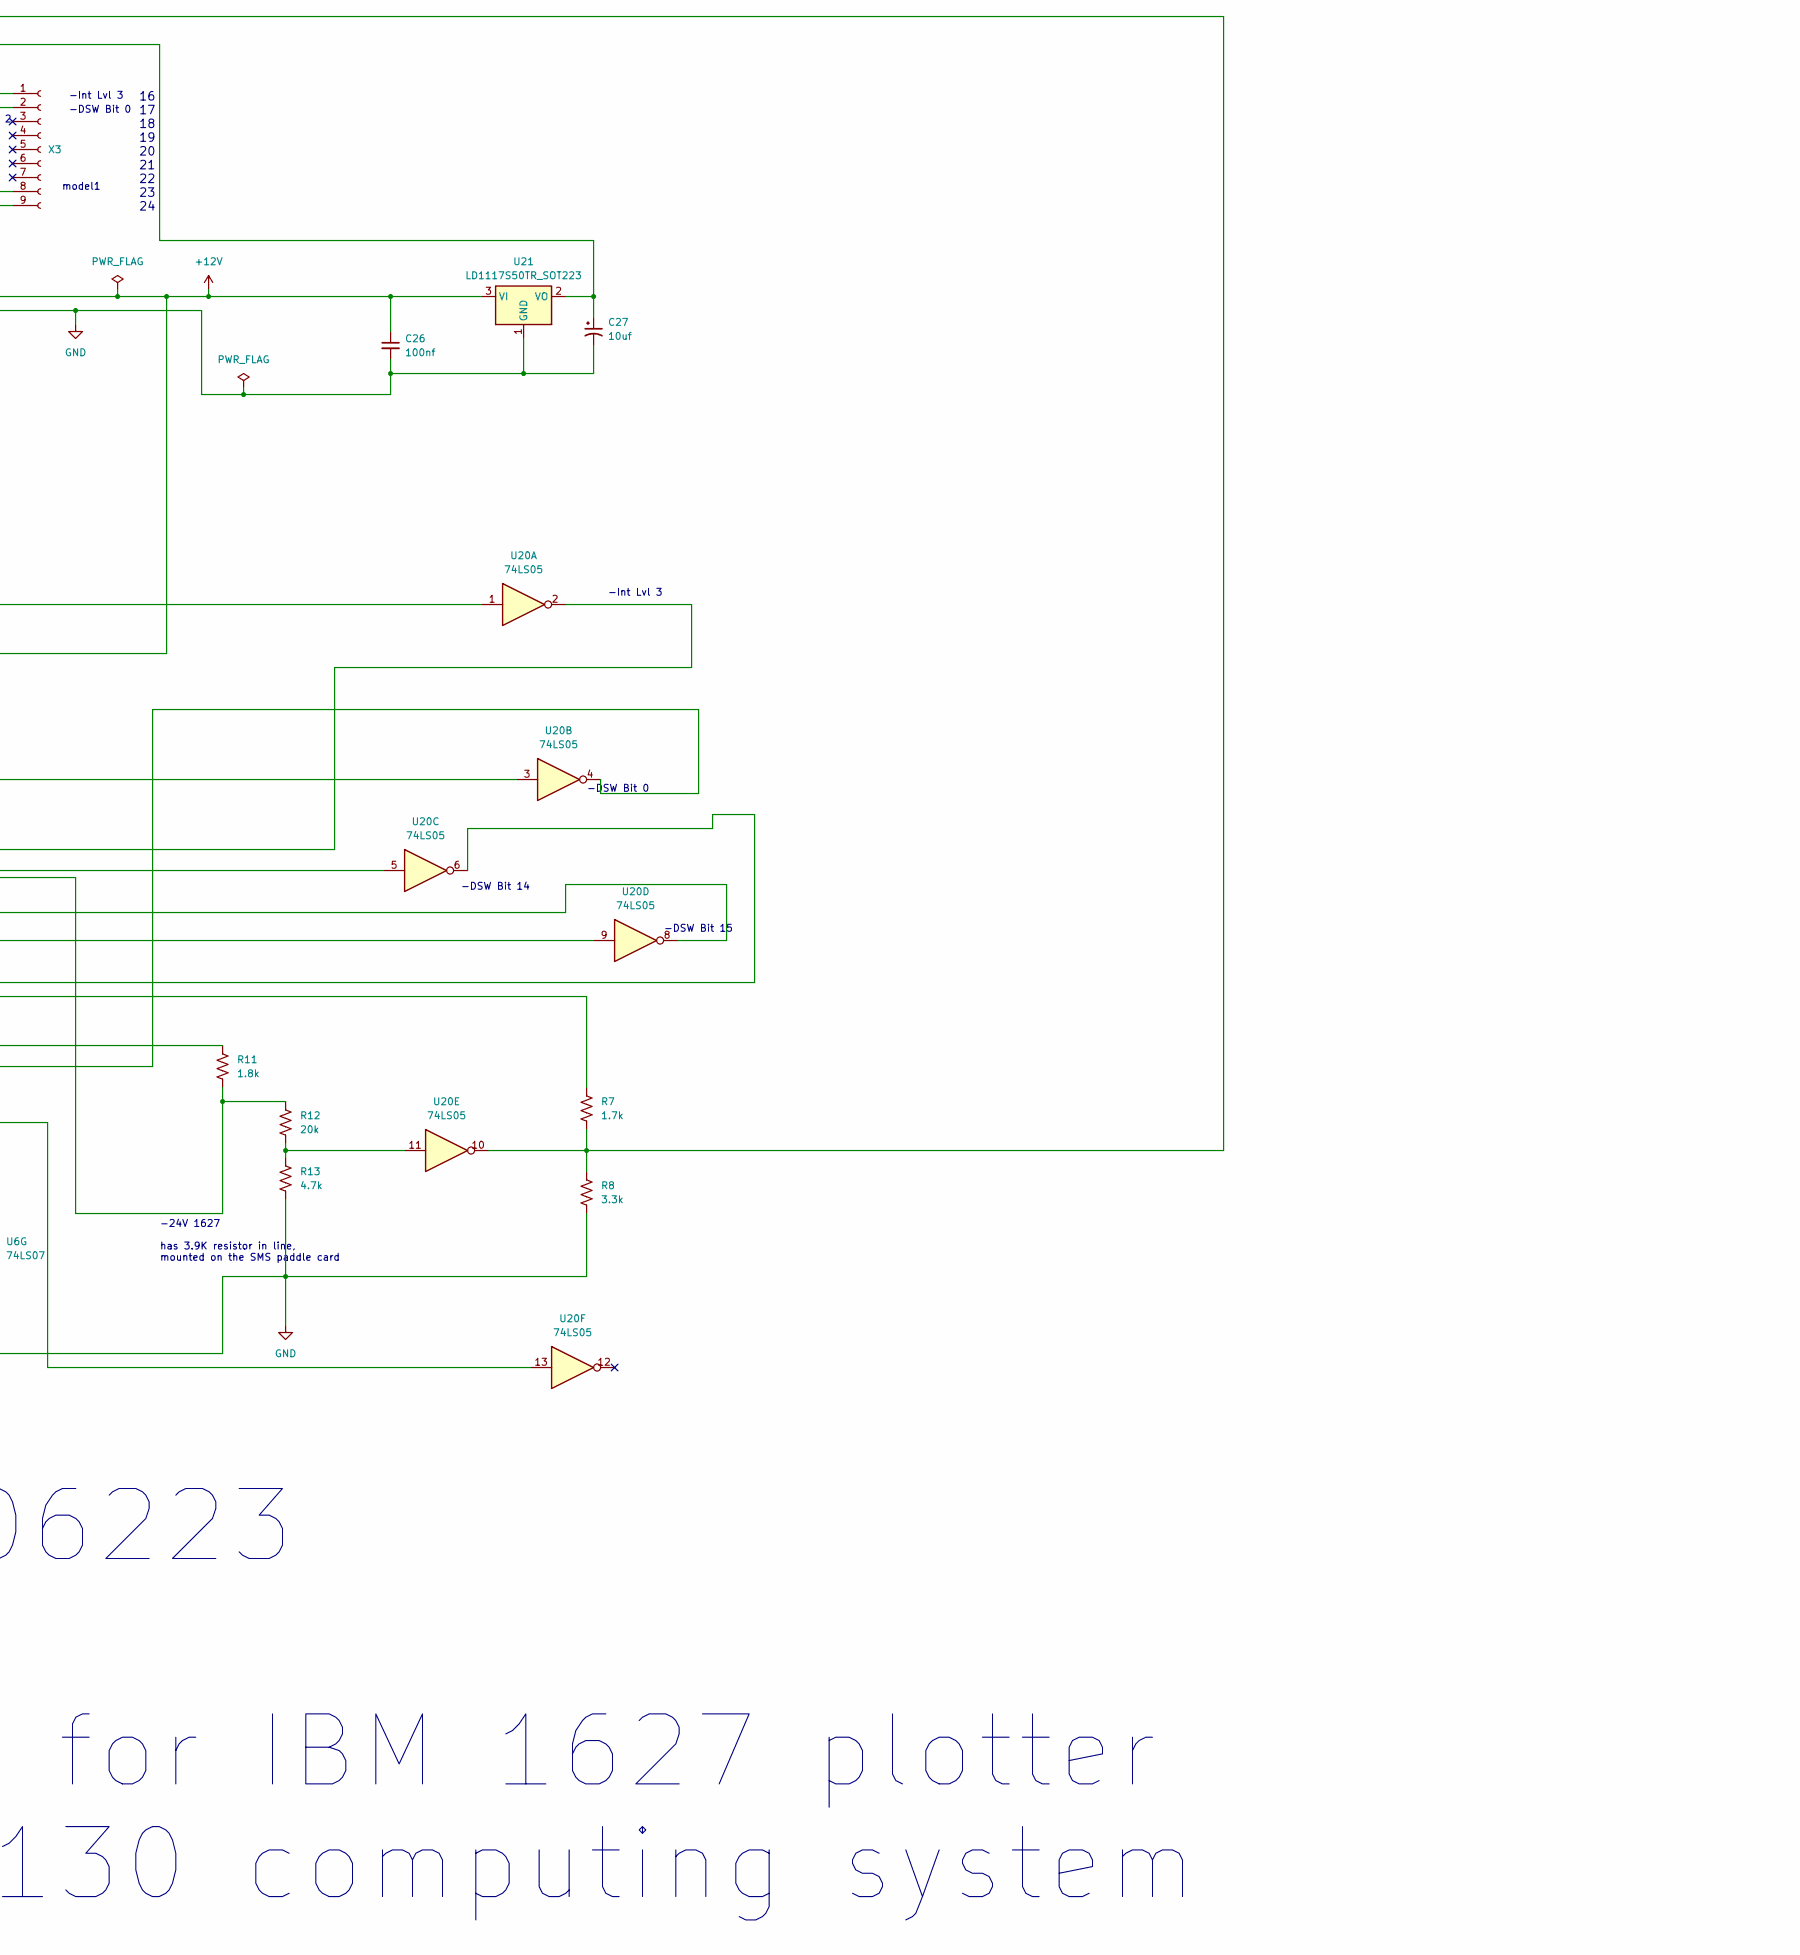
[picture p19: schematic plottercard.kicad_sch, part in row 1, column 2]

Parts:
C6, C8: .1uF; C_0805_2012Metric
C26: 100nf; C_0805_2012Metric
C27: 10uf; C_0805_2012Metric
J14: EdgeConnectorSingle; PlugConnector
J15: EdgeConnectorSingle2; PlugConnector2
J16: Conn_01x02_Pin; PinHeader_1x02_P2.54mm_Vertical
R1, R2, R3, R4, R5, R6: 1K; R_0805_2012Metric
R7: 1.7k; R_0805_2012Metric
R8: 3.3k; R_0805_2012Metric
R11: 1.8k; R_0805_2012Metric
R12: 20k; R_0805_2012Metric
R13: 4.7k; R_0805_2012Metric
U6: 74LS07; SOIC-14_3.9x8.7mm_P1.27mm
U20: 74LS05; SOIC-14_3.9x8.7mm_P1.27mm
U21: LD1117S50TR_SOT223; SOT-223-3_TabPin2
X1, X2, X3, X4: Conn_01x09_Socket; PinSocket_1x09_P2.54mm_Vertical

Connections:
+12V: C26.1, J15.G02, R1.1, R2.1, R3.1, R4.1, R5.1, R6.1, R11.1, U21.3 (VI)
GND: C6.2, C8.2, C26.2, C27.2, J14.D08, J15.J08, J16.2, R8.2, R13.2, U6.7 (GND), U20.7 (GND), U21.1 (GND), X4.9
unnamed: J14.B04, U20.6
unnamed: J14.B05, U20.8
unnamed: J14.B08, R11.2, R12.1
unnamed: J14.B09, U20.2
unnamed: J14.B10, U20.4
unnamed: J14.D04, R5.2, U6.12
unnamed: J14.D05, R6.2, U6.8
unnamed: J15.G05, R3.2, U6.6
unnamed: J15.J02, R2.2, U6.4
unnamed: J15.J04, R4.2, U6.10
unnamed: J15.J05, R1.2, U6.2
unnamed: J16.1, X3.8
unnamed: R12.2, R13.1, U20.11
unnamed: C6.1, C8.1, C27.1, R7.1, U6.14 (VCC), U20.13, U20.14 (VCC), U21.2 (VO), X3.9
unnamed: J15.J12, X1.1
unnamed: J15.J10, X1.2
unnamed: J15.J13, X1.3
unnamed: J14.D12, X1.4
unnamed: J14.B03, X1.5
unnamed: J14.D10, X1.6
unnamed: J14.D02, X1.7
unnamed: J14.D13, X1.8
unnamed: J14.D06, X1.9
unnamed: U6.1, X2.1
unnamed: U6.3, X2.2
unnamed: U6.5, X2.3
unnamed: U6.11, X2.4
unnamed: U6.13, X2.5
unnamed: U6.9, X2.6
unnamed: J14.B02, X2.7
unnamed: U20.1, X3.1
unnamed: U20.3, X3.2
unnamed: U20.5, X4.3
unnamed: U20.9, X4.4
unnamed: J14.D09, X4.5
unnamed: J14.D07, J14.D11, X4.6
unnamed: R7.2, R8.1, U20.10, X4.8

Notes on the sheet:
-B Bit 2
jumper installed on J1 if 1627 model 2 or Calcomp 563 is attached
-Down
-B Bit 3
-UP
Substitute card for IBM 5806223 Implements controller logic for IBM 1627 plotter when attached to an IBM 1130 computing system
-DSW Bit 15
16 17 18 19 20 21 22 23 24
-B Bit 1
-Pen Up
-Right
1 2 3 4 5 6 7 8 9
-Pen Down
+XIO Sense Reset 15
Plotter attached
-DSW Bit 0
-DSW Bit 14
48 47 46 45 44 43 42 41 40
-Left
-24V 1627 has 3.9K resistor in line, mounted on the SMS paddle card
model1
+Area 5
33 32 31 30 29 28 27 26 25
+T6
-Int Lvl 3
+XIO Write
-DC Reset
-B Bit 4
-B Bit 0
+XIO Sense Device
-B Bit 5

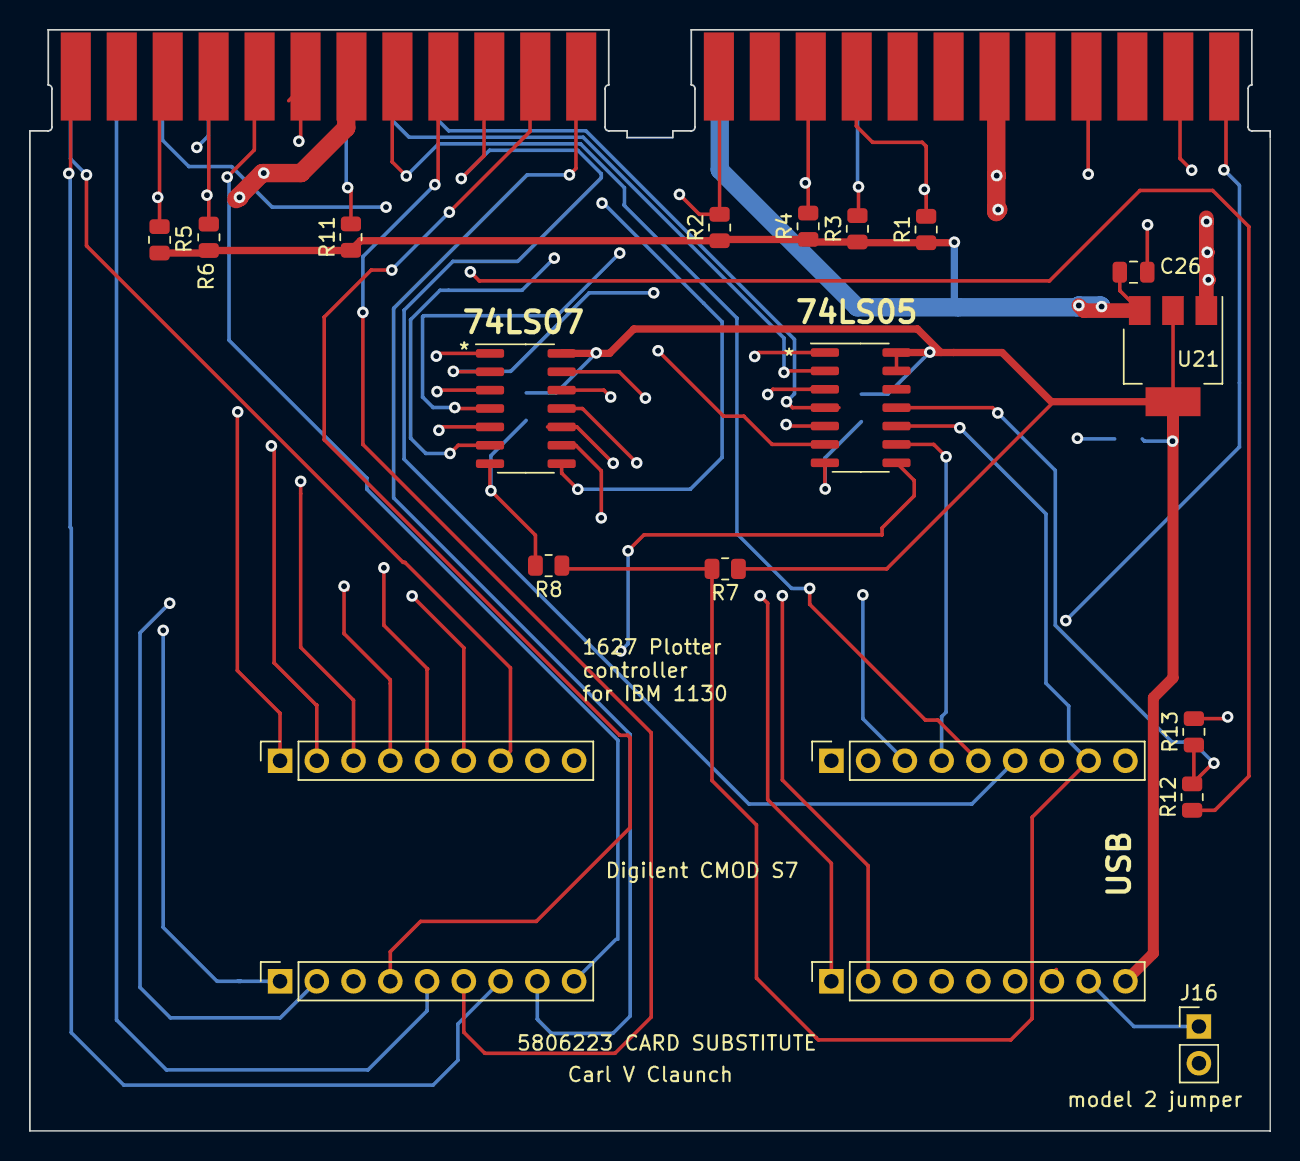
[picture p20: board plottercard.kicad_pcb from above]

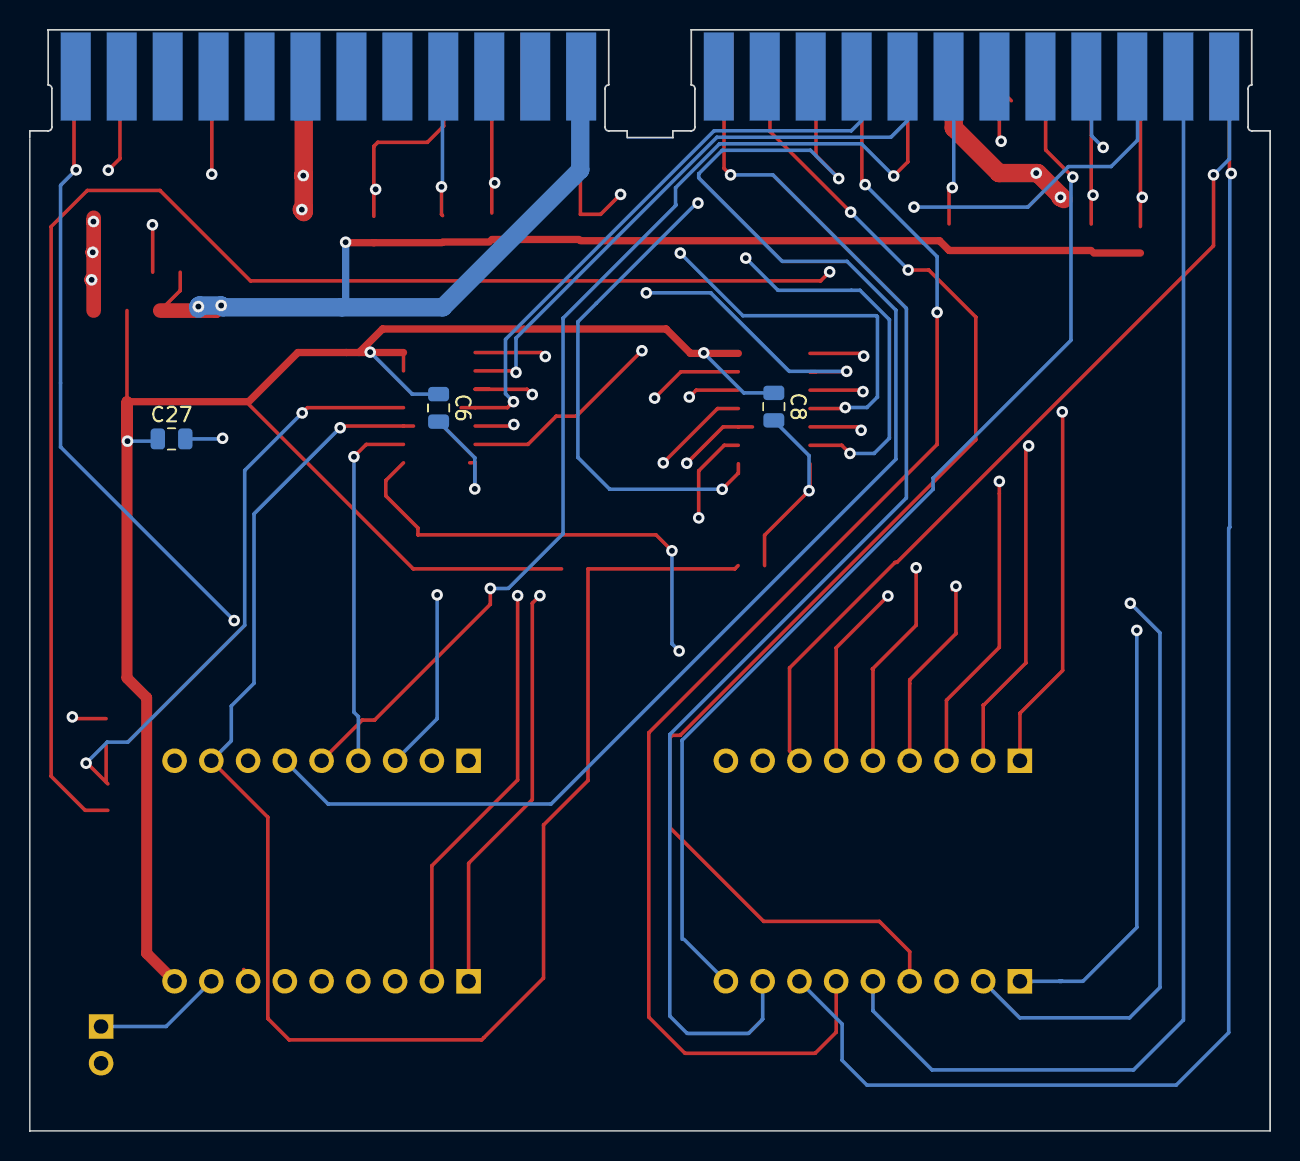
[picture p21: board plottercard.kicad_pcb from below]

Board: 4 copper layers, 85.7 x 76.1 mm, 25 parts (3 on the bottom side), 39 nets.

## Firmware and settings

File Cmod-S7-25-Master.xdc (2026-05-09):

## This file is a general .xdc for the Cmod S7-25 Rev. B
## To use it in a project:
## - uncomment the lines corresponding to used pins
## - rename the used ports (in each line, after get_ports) according to the top level signal names in the project

## 12 MHz System Clock
set_property -dict { PACKAGE_PIN M9    IOSTANDARD LVCMOS33 } [get_ports { clk }]; #IO_L13P_T2_MRCC_14 Sch=gclk
create_clock -add -name sys_clk_pin -period 83.33 -waveform {0 41.66} [get_ports { clk }];

## Push Buttons
#set_property -dict { PACKAGE_PIN D2    IOSTANDARD LVCMOS33 } [get_ports { btn[0] }]; #IO_L6P_T0_34 Sch=btn[0]
#set_property -dict { PACKAGE_PIN D1    IOSTANDARD LVCMOS33 } [get_ports { btn[1] }]; #IO_L6N_T0_VREF_34 Sch=btn[1]

## RGB LEDs
#set_property -dict { PACKAGE_PIN F1    IOSTANDARD LVCMOS33 } [get_ports { led0_b }]; #IO_L10N_T1_34 Sch=led0_b
#set_property -dict { PACKAGE_PIN D3    IOSTANDARD LVCMOS33 } [get_ports { led0_g }]; #IO_L9N_T1_DQS_34 Sch=led0_g
#set_property -dict { PACKAGE_PIN F2    IOSTANDARD LVCMOS33 } [get_ports { led0_r }]; #IO_L10P_T1_34 Sch=led0_r

## 4 LEDs
#set_property -dict { PACKAGE_PIN E2    IOSTANDARD LVCMOS33 } [get_ports { led[0] }]; #IO_L8P_T1_34 Sch=led[1]
#set_property -dict { PACKAGE_PIN K1    IOSTANDARD LVCMOS33 } [get_ports { led[1] }]; #IO_L16P_T2_34 Sch=led[2]
#set_property -dict { PACKAGE_PIN J1    IOSTANDARD LVCMOS33 } [get_ports { led[2] }]; #IO_L16N_T2_34 Sch=led[3]
#set_property -dict { PACKAGE_PIN E1    IOSTANDARD LVCMOS33 } [get_ports { led[3] }]; #IO_L8N_T1_34 Sch=led[4]

## Pmod Header JA
#set_property -dict { PACKAGE_PIN J2    IOSTANDARD LVCMOS33 } [get_ports { ja[0] }]; #IO_L14P_T2_SRCC_34 Sch=ja[1]
#set_property -dict { PACKAGE_PIN H2    IOSTANDARD LVCMOS33 } [get_ports { ja[1] }]; #IO_L14N_T2_SRCC_34 Sch=ja[2]
#set_property -dict { PACKAGE_PIN H4    IOSTANDARD LVCMOS33 } [get_ports { ja[2] }]; #IO_L13P_T2_MRCC_34 Sch=ja[3]
#set_property -dict { PACKAGE_PIN F3    IOSTANDARD LVCMOS33 } [get_ports { ja[3] }]; #IO_L11N_T1_SRCC_34 Sch=ja[4]
#set_property -dict { PACKAGE_PIN H3    IOSTANDARD LVCMOS33 } [get_ports { ja[4] }]; #IO_L13N_T2_MRCC_34 Sch=ja[7]
#set_property -dict { PACKAGE_PIN H1    IOSTANDARD LVCMOS33 } [get_ports { ja[5] }]; #IO_L12P_T1_MRCC_34 Sch=ja[8]
#set_property -dict { PACKAGE_PIN G1    IOSTANDARD LVCMOS33 } [get_ports { ja[6] }]; #IO_L12N_T1_MRCC_34 Sch=ja[9]
#set_property -dict { PACKAGE_PIN F4    IOSTANDARD LVCMOS33 } [get_ports { ja[7] }]; #IO_L11P_T1_SRCC_34 Sch=ja[10]

## USB UART
## Note: Port names are from the perspoctive of the FPGA.
set_property -dict { PACKAGE_PIN L12   IOSTANDARD LVCMOS33 } [get_ports { uart_tx }]; #IO_L6N_T0_D08_VREF_14 Sch=uart_rxd_out
set_property -dict { PACKAGE_PIN K15   IOSTANDARD LVCMOS33 } [get_ports { uart_rx }]; #IO_L5N_T0_D07_14 Sch=uart_txd_in

## Analog Inputs on PIO Pins 32 and 33
#set_property -dict { PACKAGE_PIN A13   IOSTANDARD LVCMOS33 } [get_ports { vaux5_p }]; #IO_L12P_T1_MRCC_AD5P_15 Sch=ain_p[32]
#set_property -dict { PACKAGE_PIN A14   IOSTANDARD LVCMOS33 } [get_ports { vaux5_n }]; #IO_L12N_T1_MRCC_AD5N_15 Sch=ain_n[32]
#set_property -dict { PACKAGE_PIN A11   IOSTANDARD LVCMOS33 } [get_ports { vaux12_p }]; #IO_L11P_T1_SRCC_AD12P_15 Sch=ain_p[33]
#set_property -dict { PACKAGE_PIN A12   IOSTANDARD LVCMOS33 } [get_ports { vaux12_n }]; #IO_L11N_T1_SRCC_AD12N_15 Sch=ain_n[33]
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

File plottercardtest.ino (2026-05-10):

//
//  drive the bench test of the 5806223 card replacement that is the controller
//  for the IBM 1627 plotter models 1 or 2, as well as the Calcomp 565 and 563
//
//  uses direct port access for the digital writes to operate fast enough
//  to bitbang the memory access cycles from the IBM 1130 computer
//  that occur to drive the card with commands to the plotter
//  or sense requests, interrupt resets and overall card resets
//
//  designed for an Arduino Uno - if a different controller used,
//  port mapping may change and need to be reflected in the code 
//
//
// port D bits 2 to 7 below
#define T6 2
#define XIOS 3
#define XIOS15 4
#define DCRESET 5
#define B0 6
#define B1 7
// port B bits 0 to 5 below
#define B2 8
#define B3 9
#define B4 10
#define B5 11
#define XIOW 12
#define A5 13
// reuse analog inputs as digital inputs for buttons 
#define resetit A0
#define doup A1
#define doraise A2
#define sense A3
#define sensereset A4
#define doboth 19

// digital pin direct access snippets
// inserted into bit manipulation statemens
// against PORTD or PORTB to control outputs
#define PIN2 (1 << 2)
#define PIN3 (1 << 3)
#define PIN4 (1 << 4)
#define PIN5 (1 << 5)
#define PIN6 (1 << 6)
#define PIN7 (1 << 7)
#define PIN8 (1 << 0)
#define PIN9 (1 << 1)
#define PIN10 (1 << 2)
#define PIN11 (1 << 3)
#define PIN12 (1 << 4)
#define PIN13 (1 << 5)

void setup() {
  // set the state of the digital pins 2-13
  // and the five analog pins A0-A5 (14-19)
  pinMode (XIOW, OUTPUT);
  pinMode (A5, OUTPUT);
  pinMode (T6, OUTPUT);
  pinMode (XIOS, OUTPUT);
  pinMode (XIOS15, OUTPUT);
  pinMode (DCRESET, OUTPUT);
  pinMode (B0, OUTPUT);
  pinMode (B1, OUTPUT);
  pinMode (B2, OUTPUT);
  pinMode (B3, OUTPUT);
  pinMode (B4, OUTPUT);
  pinMode (B5, OUTPUT);

  // set the states of the six button inputs
  // that request specific actions from this code
  pinMode (resetit, INPUT_PULLUP);
  pinMode (doup, INPUT_PULLUP);
  pinMode (doraise, INPUT_PULLUP);
  pinMode (sense, INPUT_PULLUP);
  pinMode (sensereset, INPUT_PULLUP);
  pinMode (doboth, INPUT_PULLUP);

  // begin with card in reset state (inverted logic)
  digitalWrite(DCRESET, LOW);

  // now set the output initial states
  // below control inputs are standard, true when high
  digitalWrite(XIOW, LOW);
  digitalWrite(A5, LOW);
  digitalWrite(T6, LOW);
  digitalWrite(XIOS, LOW);
  digitalWrite(XIOS15, LOW);
  // below control inputs are inverted, true when low
  digitalWrite(B0, HIGH);
  digitalWrite(B1, HIGH);
  digitalWrite(B2, HIGH);
  digitalWrite(B3, HIGH);
  digitalWrite(B4, HIGH);
  digitalWrite(B5, HIGH);
  delay(500);

  // release the reset from the board
  digitalWrite(DCRESET, HIGH);

  // open diagnostic serial link
  Serial.begin(9600);
  Serial.println("Testbed ready"); 
}

void loop() {
  // process any button pushes 
  if (digitalRead(resetit) == HIGH) {
    // hold reset for half a second then release
    digitalWrite(DCRESET, LOW);
    delay(500);
    digitalWrite(DCRESET, HIGH);
    Serial.println("card reset");
    delay (1500);      // debounce time for my finger on button
  } else if (digitalRead(sense) == HIGH) {
    // simulate the 1130 executing an XIO Sense Device for plotter
    // one memory cycle (8 T clock steps)
    PORTD |= PIN3; // XIOS
    PORTB |= PIN13; // A5
    PORTB |= PIN13; // A5
    PORTB |= PIN13; // A5
    PORTB |= PIN13; // A5
    PORTB |= PIN13; // A5
    PORTB |= PIN13; // A5
    PORTB |= PIN13; // A5
    PORTB |= PIN13; // A5
    PORTD &= ~PIN3; // ~XIOS
    PORTB &= ~PIN13; // ~A5
    Serial.println("Sense");
    delay (2000);      // debounce time for my finger on button
  } else if (digitalRead(sensereset) == HIGH) {
    // simulate an XIO Sense Device with reset bit 15 turned on
    // one memory cycle (8 T clock steps)
    PORTD |= PIN3; // XIOS
    PORTB |= PIN13; // A5
    PORTD |= PIN4; // XIOS15
    PORTB |= PIN13; // A5
    PORTB |= PIN13; // A5
    PORTB |= PIN13; // A5
    PORTB |= PIN13; // A5
    PORTB |= PIN13; // A5
    PORTD &= ~PIN3; // ~XIOS
    PORTD &= ~PIN4; // ~XIOS15
    PORTB &= ~PIN13; // ~A5
    Serial.println("Sense Reset 15");
    delay (2000);      // debounce time for my finger on button
  } else if (digitalRead(doup) == HIGH) {
    // simulate an XIO Write with B Bit 2 set (move drumup)
    // one memory cycle but only activates at T6 clock step
    PORTB |= PIN12; // XIOW
    PORTB |= PIN13; // A5
    PORTB &= ~PIN8; // ~B2
    PORTB &= ~PIN8; // ~B2
    PORTB &= ~PIN8; // ~B2
    PORTB &= ~PIN8; // ~B2
    PORTD |= PIN2; // T6
    PORTD &= ~PIN2; // ~T6
    PORTB &= ~PIN13; // ~A5
    PORTB &= ~PIN12; // ~XIOW
    PORTB |= PIN8; // B2
    // wait 1 millisecond then execute XIO Sense Device
    delay(1);
    PORTD |= PIN3; // XIOS
    PORTB |= PIN13; // A5
    PORTB |= PIN13; // A5
    PORTB |= PIN13; // A5
    PORTB |= PIN13; // A5
    PORTB |= PIN13; // A5
    PORTB |= PIN13; // A5
    PORTB |= PIN13; // A5
    PORTD &= ~PIN3; // ~XIOS
    PORTB &= ~PIN13; // ~A5
    Serial.println("Drum up");
    delay (2000);      // debounce time for my finger on button
  } else if (digitalRead(doraise) == HIGH) {
    // simulate an XIO Write with B Bit 5 set (raise pen off paper)
    // one memory cycle but only activates at T6 clock step
    PORTB |= PIN12; // XIOW
    PORTB |= PIN13; // A5
    PORTB &= ~PIN11; // ~B5
    PORTB &= ~PIN11; // ~B5
    PORTB &= ~PIN11; // ~B5
    PORTB &= ~PIN11; // ~B5
    PORTD |= PIN2; // T6
    PORTD &= ~PIN2; // ~T6
    PORTB &= ~PIN13; // ~A5
    PORTB &= ~PIN12; // ~XIOW
    PORTB |= PIN11; // B5
    // wait 1 millisecond then execute XIO Sense Device
    delay(1);
    PORTD |= PIN3; // XIOS
    PORTB |= PIN13; // A5
    PORTB |= PIN13; // A5
    PORTB |= PIN13; // A5
    PORTB |= PIN13; // A5
    PORTB |= PIN13; // A5
    PORTB |= PIN13; // A5
    PORTB |= PIN13; // A5
    PORTD &= ~PIN3; // ~XIOS
    PORTB &= ~PIN13; // ~A5
    Serial.println("Raise pen");
    delay (2000);      // debounce time for my finger on button
  } else if (digitalRead(doboth) == HIGH) {    
    // simulate an XIO Write with two B bits set
    // B Bit 0 (lower pen on paper) and B Bit 1 (move pen right)
    // one memory cycle but only activates at T6 clock step
    PORTB |= PIN12; // XIOW
    PORTB |= PIN13; // A5
//    PORTD &= ~PIN6; // ~B0
    PORTD &= ~PIN7; // ~B1
    PORTD &= ~PIN7; // ~B1
    PORTD |= PIN2; // T6
    PORTD &= ~PIN2; // ~T6
    PORTB &= ~PIN13; // ~A5
    PORTB &= ~PIN12; // ~XIOW
    PORTD |= PIN6; // B0
    PORTD |= PIN7; // B1
    delayMicroseconds(3900);
    PORTB |= PIN13; // A5
    PORTB |= PIN13; // A5
    PORTB |= PIN13; // A5
    PORTB |= PIN13; // A5
    PORTB |= PIN13; // A5
    PORTB |= PIN13; // A5
    PORTB |= PIN13; // A5
    PORTB |= PIN13; // A5
    PORTB |= PIN13; // A5
    PORTB |= PIN13; // A5
    PORTB |= PIN13; // A5
    PORTB |= PIN13; // A5
    PORTB |= PIN13; // A5
    PORTB |= PIN13; // A5
    PORTB |= PIN13; // A5
    PORTB |= PIN13; // A5
    PORTB |= PIN13; // A5
    PORTD |= PIN3; // XIOS
    PORTB |= PIN13; // A5
    PORTB |= PIN13; // A5
    PORTB |= PIN13; // A5
    PORTB |= PIN13; // A5
    PORTB |= PIN13; // A5
    PORTB |= PIN13; // A5
    PORTB |= PIN13; // A5
    PORTD &= ~PIN3; // ~XIOS
     PORTB &= ~PIN13; // ~A5
    delayMicroseconds(2200);
    PORTB |= PIN13; // A5
    PORTB |= PIN13; // A5
    PORTB |= PIN13; // A5
    PORTB |= PIN13; // A5
    PORTB |= PIN13; // A5
    PORTB |= PIN13; // A5
    PORTB |= PIN13; // A5
    PORTB |= PIN13; // A5
    PORTB |= PIN13; // A5
    PORTB |= PIN13; // A5
    PORTD |= PIN3; // XIOS
    PORTB |= PIN13; // A5
    PORTB |= PIN13; // A5
    PORTB |= PIN13; // A5
    PORTB |= PIN13; // A5
    PORTB |= PIN13; // A5
    PORTB |= PIN13; // A5
    PORTB |= PIN13; // A5
    PORTD &= ~PIN3; // ~XIOS
     PORTB &= ~PIN13; // ~A5
   Serial.println("Pen right and lowered");
    delay (2000);      // debounce time for my finger on button
  } // do nothing if none of the buttons were pushed
}

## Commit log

2026-03-19 Initial upload
    [plottercard.kicad_pcb, plottercard.kicad_sch]
2026-03-22 Filling out initial repository prior to testing
    [BOM.csv]
2026-05-09 After successful bench testing of the card functionality
    Includes simulation test code and code for an Arduino that drives test signals into the card on the bench.
    updated fill of materials
    verilog and configuration file for the CMOD S7 board
    [BOM.csv]
2026-05-09 PCB gerber and drill files
2026-05-09 adding PCB files for SMS power card
    Gerber and drill files to build an SMS power card
2026-05-09 adding PCB files for SMS signal paddle card
    gerber and drill files to create SMS paddle card
2026-05-10 update descriptions of plotter bench test driver code
2026-05-10 Describe method of bench testing
    Setup to bench test using Arduino Uno to drive inputs, scope to observe outputs, plus several power supplies, pullup resistors. buffer chips and connections
2026-05-10 Initial upload
    Describes how to assemble the controller card as well as various cables and connectors.
    Also covers how to test the card.
2026-05-10 Configuration memory file to load CMOD S7 board
    This file can be loaded onto the Digilent CMOD S7 board if it uses the MX25L3233F memory device. Plug the USB cable into the CMOD and into the machine running Vivado. Open the hardware, autoconnect t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
2026-05-11 Updated FPGA logic after testing in IBM 1130 system
    This logic works exactly as the original IBM card does, producing the same behaviors, waveforms, timings and voltage levels.
2026-05-11 Up to date KiCad design files
    matching the gerbers and drill files
    [plottercard.kicad_pcb, plottercard.kicad_sch]
2026-05-13 Images of the SMS signal and SMS power paddle cards
    What the PCBs will look like if built using the included gerber/drill files
2026-05-13 Acknowledge sponsorship of PCB development
    PCBWay.com covered the costs of building and shipping the main printed circuit card for this project in exchange for mention in my blog covering the project - https://rescue1130.blogspot.com/
2026-05-16 Minor edits to document
    Added warning to put power SMS paddle card only in slot PP6
2026-05-25 Update README.md
    add in mention of sponsor for the PCBs I designed for this project
